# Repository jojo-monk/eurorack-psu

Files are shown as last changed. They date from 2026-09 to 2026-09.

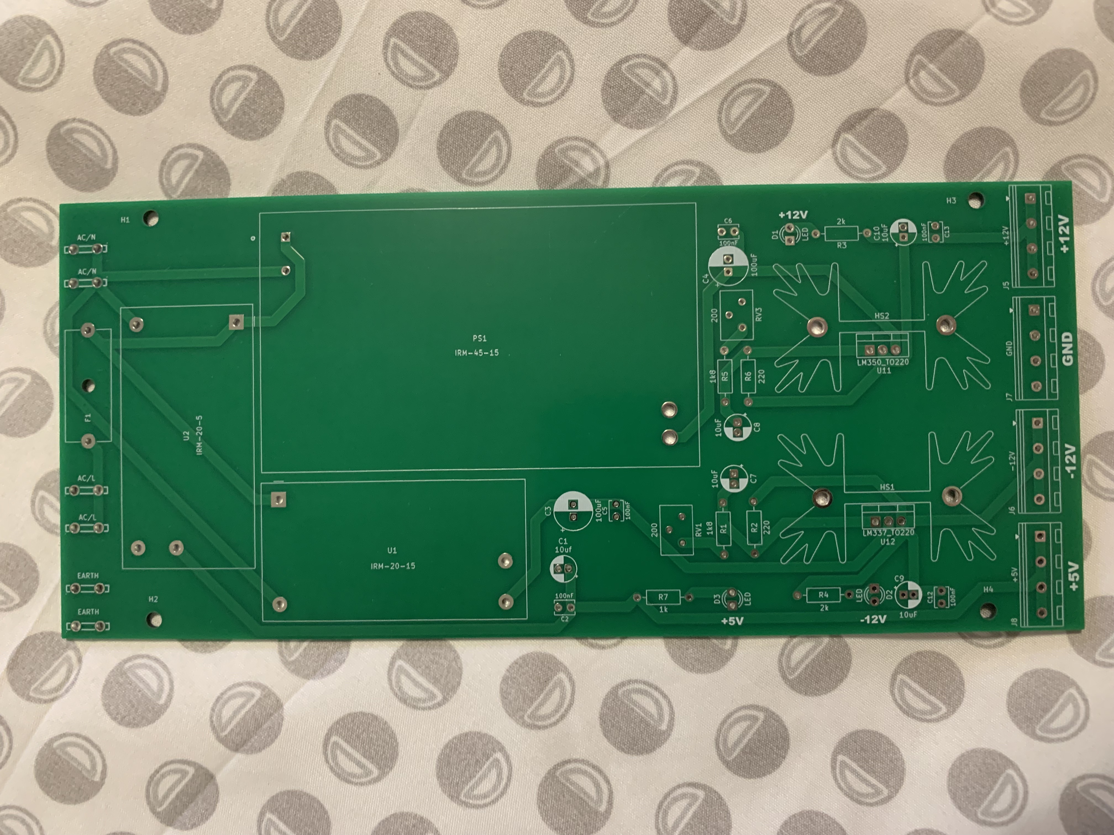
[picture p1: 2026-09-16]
Eurorack-Psu-PCB.jpeg

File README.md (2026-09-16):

# Eurorack PSU

DIY Eurorack power supply based on three **Mean Well IRM AC/DC modules**, with linear post-regulation using **LM350** and **LM337**.

The design was developed in **KiCad** specifically for Eurorack modular synthesizers, with separate power sources for the positive and negative rails and a dedicated +5 V supply.

## Features

- **+12 V / -12 V / +5 V** Eurorack power rails
- 3× isolated Mean Well IRM AC/DC modules
- Linear regulation of the ±12 V rails
- **LM350** positive voltage regulator
- **LM337** negative voltage regulator
- Dedicated +5 V supply
- Filtering and decoupling
- Heatsinks on the linear regulators
- KiCad schematic and PCB design

## Power supply architecture

The power supply uses three independent Mean Well AC/DC modules:

```text
                         AC MAINS
                            │
             ┌──────────────┼──────────────┐
             │              │              │
             ▼              ▼              ▼
        IRM-45-15       IRM-20-15       IRM-20-5
          15 V / 3 A      15 V / 1.4 A     5 V / 4 A
             │              │              │
             ▼              ▼              │
           LM350          LM337             │
             │              │              │
             ▼              ▼              ▼
           +12 V           -12 V           +5 V
             │              │              │
             └──────────────┴──────────────┘
                            │
                     Eurorack power bus
```

The two 15 V supplies are used independently for the positive and negative Eurorack rails.

The ±12 V outputs are obtained through linear regulation, providing additional filtering and regulation after the isolated AC/DC conversion stage.

## Mean Well modules

| Module | Output | Rated current | Rated power | Rail |
|---|---:|---:|---:|---|
| **IRM-45-15** | 15 V DC | 3 A | 45 W | +12 V |
| **IRM-20-15** | 15 V DC | 1.4 A | 21 W | -12 V |
| **IRM-20-5** | 5 V DC | 4 A | 20 W | +5 V |

The three AC/DC modules provide a combined nominal power of approximately **86 W** before linear regulation losses.

## Output specifications

| Rail | Regulation | Maximum current* | Maximum output power* |
|---|---|---:|---:|
| **+12 V** | LM350 | 3 A | 36 W |
| **-12 V** | LM337 | 1.4 A | 16.8 W |
| **+5 V** | IRM-20-5 | 4 A | 20 W |
| **Total** | | | **72.8 W** |

\* The values for the ±12 V rails are theoretical maximums based on the nominal output current of the corresponding Mean Well modules. Actual continuous output capability depends on thermal conditions, heatsink installation, PCB design and ambient temperature.

## Thermal considerations

The ±12 V rails use linear regulators, which dissipate the voltage difference between the 15 V input and the regulated 12 V output as heat.

## PCB

The PCB was designed using **KiCad**.

The repository contains the design files and manufacturing data for the power supply.

## Interactive BOM

The interactive Bill of Materials is available online:

**[🔧 Open Interactive BOM](https://jojo-monk.github.io/eurorack-psu/ibom.html)**

## Project status

**Built, tested and fully functional.**

The power supply has been successfully assembled, tested and validated in operation. All three output rails (**+12 V, -12 V and +5 V**) have been tested and the power supply is fully operational in a Eurorack system.

## Safety

> [!WARNING]
> **MAINS VOLTAGE**
>
> This power supply is directly connected to the AC mains.
>
> Mains voltage can cause serious injury or death. This project should only be built and tested by people familiar with mains electrical safety.
>
> The finished power supply must be installed in a suitable enclosure with:
>
> - proper mains insulation
> - protective earth where required
> - appropriate fusing
> - strain relief
> - adequate spacing between mains and low-voltage circuitry
> - protection against accidental contact with mains voltage
>
> Do not operate the PCB exposed when connected to the mains.

## Project status

This is a DIY Eurorack power supply developed for personal experimentation and modular synthesizer projects.

The design is provided as-is. Always verify the actual output voltages, current capability and thermal performance of the assembled unit before connecting Eurorack modules.

## License


License
This project is licensed under the Creative Commons Attribution-NonCommercial-ShareAlike 4.0 International (CC BY-NC-SA 4.0) license.
Copyright © 2026 Johann Moine
You are free to:
Share — copy and redistribute the material
Adapt — remix, transform and build upon the material
Under the following conditions:
Attribution — You must give appropriate credit to the original author, provide a link to the license, and indicate if changes were made.
NonCommercial — You may not use the material for commercial purposes.
ShareAlike — If you remix, transform, or build upon the material, you must distribute your contributions under the same license.
See the full license:
Creative Commons BY-NC-SA 4.0

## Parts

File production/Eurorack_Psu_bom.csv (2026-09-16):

Designator | Footprint | Quantity | Value | LCSC Part #
C1, C10, C7, C8, C9 | CP_Radial_D5.0mm_P2.00mm | 5 | 10uf
C12, C13, C2, C5, C6 | Capacitor_Disc_D3.8mm_W2.6mm_P2.50mm | 5 | 100nF
C3, C4 | CP_Radial_D7.5mm_P2.50mm | 2 | 100uF
D1, D2, D3 | LED_D3.0mm | 3 | LED
F1 | Fuseholder_Cylinder-5x20mm_Schurter_0031_8201_Horizontal_Open | 1 | Fuse
HS1, HS2 | Heatsink_Fischer_SK129-STS_42x25mm_2xDrill2.5mm | 2 | Heatsink
J1 | TerminalBlock_RND_205-00002_1x03_P5.00mm_Horizontal | 1 | +12V
J2 | TerminalBlock_RND_205-00002_1x03_P5.00mm_Horizontal | 1 | -12V
J3 | TerminalBlock_RND_205-00002_1x03_P5.00mm_Horizontal | 1 | GND
J4 | TerminalBlock_RND_205-00002_1x03_P5.00mm_Horizontal | 1 | +5V
R1, R5 | R_Axial_DIN0207_L6.3mm_D2.5mm_P10.16mm_Horizontal | 2 | 1k8
R2, R6 | R_Axial_DIN0207_L6.3mm_D2.5mm_P10.16mm_Horizontal | 2 | 220
R3, R4 | R_Axial_DIN0207_L6.3mm_D2.5mm_P10.16mm_Horizontal | 2 | 2k
R7 | R_Axial_DIN0207_L6.3mm_D2.5mm_P10.16mm_Horizontal | 1 | 1k
RV1, RV3 | Potentiometer_Bourns_3299Y_Vertical | 2 | 200
U1 | Converter_ACDC_MeanWell_IRM-20-xx_THT | 1 | IRM-20-15
U11 | TO-220-3_Vertical | 1 | LM350_TO220
U12 | TO-220-3_Vertical | 1 | LM337_TO220
U13, U6 | CONN-TH_726386-2 | 2 | EARTH | C305817
U2 | Converter_ACDC_MeanWell_IRM-20-xx_THT | 1 | IRM-20-5
U22, U3 | CONN-TH_726386-2 | 2 | AC/L | C305817
U23, U5 | CONN-TH_726386-2 | 2 | AC/N | C305817
U4 | PWRM-TH_IRM-30-12 | 1 | IRM-30-15 | C193295

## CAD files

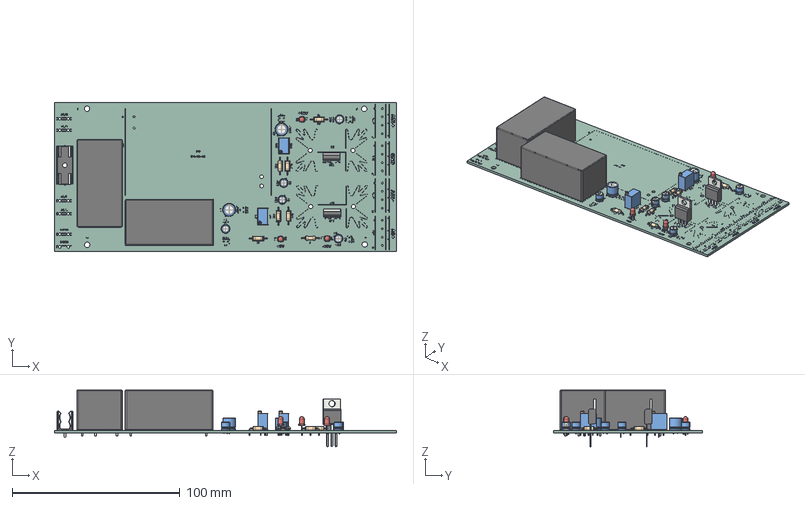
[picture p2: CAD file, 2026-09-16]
alimPCB.step
203.8 x 88.6 x 33.9 mm
Bourns_3299Y x 2
CP_Radial_D50mm_P200mm x 5
LED_D3.0mm x 3
R_Axial_DIN0207_L63mm_D25mm_P1016mm_Horizontal x 7
Converter_ACDC_MeanWell_IRM_20_xx_THT x 2
A_Schurter_0031_8201
CP_Radial_D75mm_P250mm x 2
TO-220-3_Vertical x 2
Alim_Eurorack_silkscreen
Alim_Eurorack_PCB

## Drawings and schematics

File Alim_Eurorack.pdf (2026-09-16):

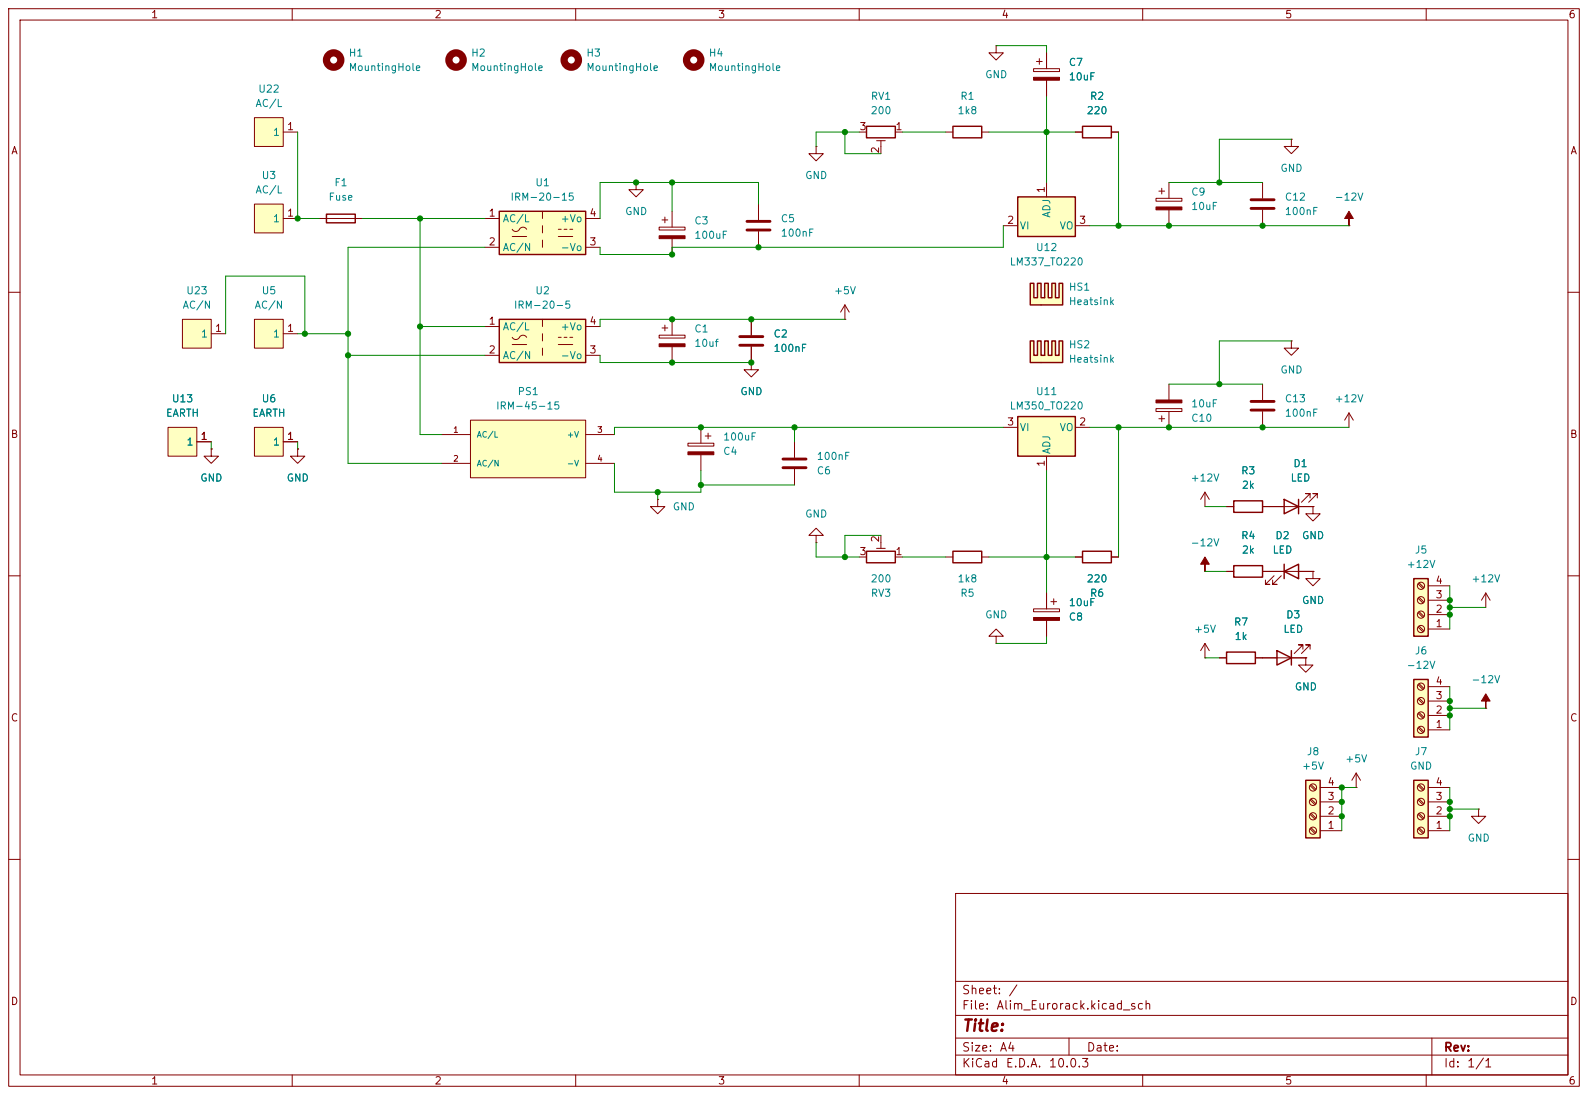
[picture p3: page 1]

Size: A4 | Rev:
KiCad E.D.A. 10.0.3 | Id: 1/1

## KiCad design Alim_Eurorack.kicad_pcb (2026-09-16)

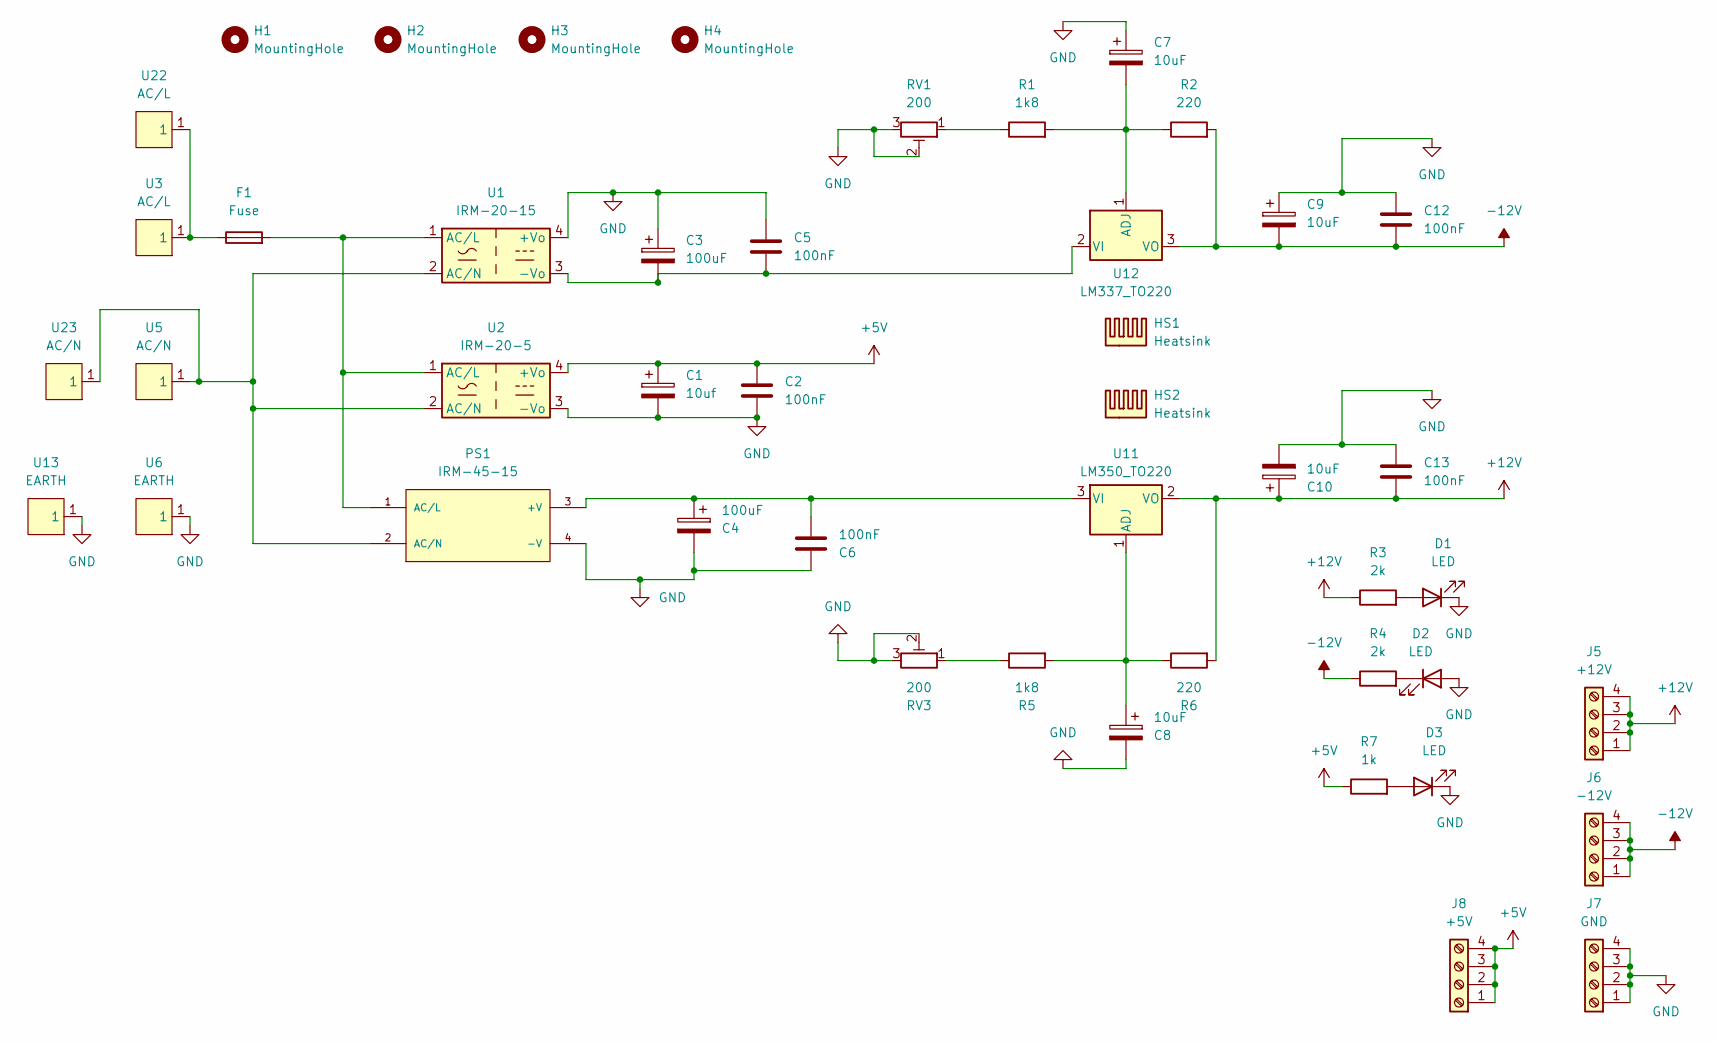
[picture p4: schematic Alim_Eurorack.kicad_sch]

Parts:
C1: 10uf; CP_Radial_D5.0mm_P2.00mm
C2, C5, C6, C12, C13: 100nF; Capacitor_Disc_D3.8mm_W2.6mm_P2.50mm
C3, C4: 100uF; CP_Radial_D7.5mm_P2.50mm
C7, C8, C9, C10: 10uF; CP_Radial_D5.0mm_P2.00mm
D1, D2, D3: LED; LED_D3.0mm
F1: Fuse; Fuseholder_Cylinder-5x20mm_Schurter_0031_8201_Horizontal_Op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
H1, H2, H3, H4: MountingHole; MountingHole_3.2mm_M3
HS1, HS2: Heatsink; Heatsink_Fischer_SK129-STS_42x25mm_2xDrill2.5mm
J5: +12V; TerminalBlock_RND_205-00047_1x04_P5.00mm_Horizontal
J6: -12V; TerminalBlock_RND_205-00047_1x04_P5.00mm_Horizontal
J7: GND; TerminalBlock_RND_205-00047_1x04_P5.00mm_Horizontal
J8: +5V; TerminalBlock_RND_205-00047_1x04_P5.00mm_Horizontal
PS1: IRM-45-15; CONV_IRM-45-15
R1, R5: 1k8; R_Axial_DIN0207_L6.3mm_D2.5mm_P10.16mm_Horizontal
R2, R6: 220; R_Axial_DIN0207_L6.3mm_D2.5mm_P10.16mm_Horizontal
R3, R4: 2k; R_Axial_DIN0207_L6.3mm_D2.5mm_P10.16mm_Horizontal
R7: 1k; R_Axial_DIN0207_L6.3mm_D2.5mm_P10.16mm_Horizontal
RV1, RV3: 200; Potentiometer_Bourns_3299Y_Vertical
U1: IRM-20-15; Converter_ACDC_MeanWell_IRM-20-xx_THT
U2: IRM-20-5; Converter_ACDC_MeanWell_IRM-20-xx_THT
U3, U22: AC/L; CONN-TH_726386-2; MPN 726386-2; LCSC Part C305817
U5, U23: AC/N; CONN-TH_726386-2; MPN 726386-2; LCSC Part C305817
U6, U13: EARTH; CONN-TH_726386-2; MPN 726386-2; LCSC Part C305817
U11: LM350_TO220; TO-220-3_Vertical
U12: LM337_TO220; TO-220-3_Vertical

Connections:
+5V: C1.1, C2.1, J8.1, J8.2, J8.3, J8.4, R7.1, U2.4 (+Vo)
+12V: C10.1, C13.2, J5.1, J5.2, J5.3, J5.4, R3.1, R6.2, U11.2 (VO)
-12V: C9.2, C12.2, J6.1, J6.2, J6.3, J6.4, R2.2, R4.1, U12.3 (VO)
GND: C1.2, C2.2, C3.1, C4.2, C5.1, C6.1, C7.1, C8.2, C9.1, C10.2, C12.1, C13.1, D1.1 (K), D2.2 (A), D3.1 (K), J7.1, J7.2, J7.3, J7.4, PS1.4 (-V), RV1.2, RV1.3, RV3.2, RV3.3, U1.4 (+Vo), U2.3 (-Vo), U6.1 (1_1), U13.1 (1_1)
unnamed: D1.2 (A), R3.2
unnamed: D2.1 (K), R4.2
unnamed: D3.2 (A), R7.2
unnamed: F1.1, U3.1 (1_1), U22.1 (1_1)
unnamed: C4.1, C6.2, PS1.3 (+V), U11.3 (VI)
unnamed: F1.2, PS1.1 (AC/L), U1.1 (AC/L), U2.1 (AC/L)
unnamed: PS1.2 (AC/N), U1.2 (AC/N), U2.2 (AC/N), U5.1 (1_1), U23.1 (1_1)
unnamed: R1.1, RV1.1
unnamed: R5.1, RV3.1
unnamed: C3.2, C5.2, U1.3 (-Vo), U12.2 (VI)
unnamed: C8.1, R5.2, R6.1, U11.1 (ADJ)
unnamed: C7.2, R1.2, R2.1, U12.1 (ADJ)

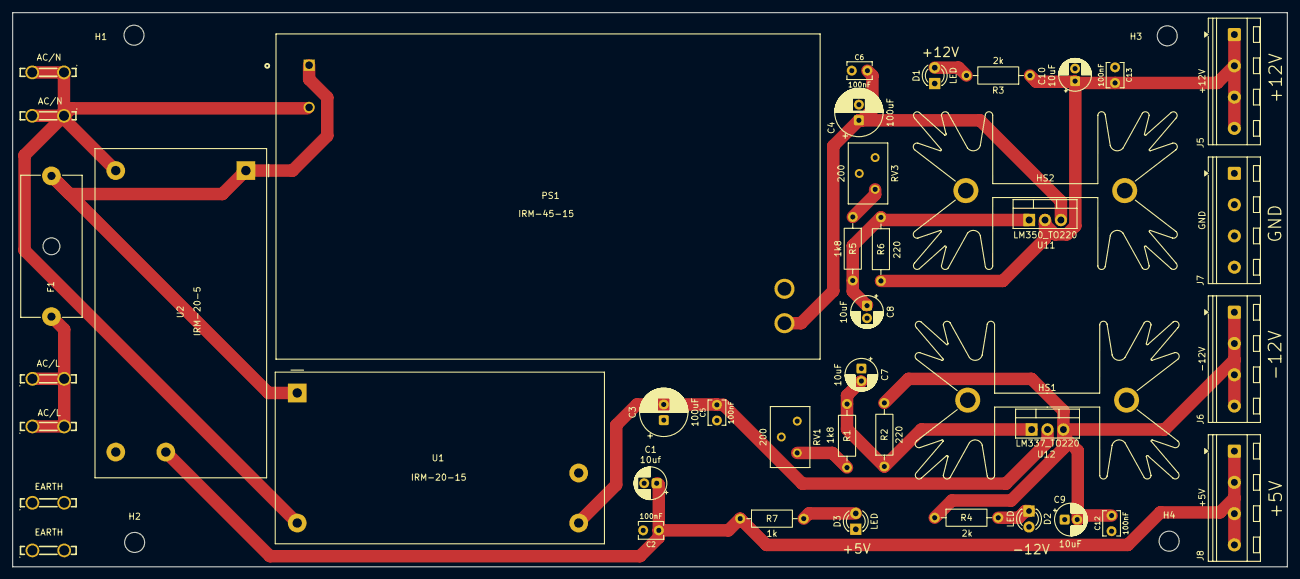
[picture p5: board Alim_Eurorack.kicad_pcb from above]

Board: 2 copper layers, 203.8 x 88.6 mm, 46 parts (0 on the bottom side), 16 nets.

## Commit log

2026-09-16 Premier commit
    [Alim_Eurorack.kicad_pcb, Alim_Eurorack.kicad_sch, Eurorack_PsuV2_bom.csv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]
2026-09-16 Add interactive BOM
2026-09-16 Add interactive BOM section to README
    Added a section for the interactive Bill of Materials with a link.
2026-09-16 Update README and add PCB image
